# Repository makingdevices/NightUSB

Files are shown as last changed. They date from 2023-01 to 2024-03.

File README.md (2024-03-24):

<!-- Improved compatibility of back to top link: See: https://github.com/othneildrew/Best-README-Template/pull/73 -->

<!--
*** Thanks for checking out the Best-README-Template. If you have a suggestion
*** that would make this better, please fork the repo and create a pull request
*** or simply open an issue with the tag "enhancement".
*** Don't forget to give the project a star!
*** Thanks again! Now go create something AMAZING! :D
-->

<!-- PROJECT SHIELDS -->
<!--
*** I'm using markdown "reference style" links for readability.
*** Reference links are enclosed in brackets [ ] instead of parentheses ( ).
*** See the bottom of this document for the declaration of the reference variables
*** for contributors-url, forks-url, etc. This is an optional, concise syntax you may use.
*** https://www.markdownguide.org/basic-syntax/#reference-style-links
-->
[][ig-url]
[][sponsor-url]
[][stars-url]
[][issues-url]
[][linkedin-url]

<!-- PROJECT LOGO -->
<br />
<div align="center">
  <a href="https://makingdevices.com/links/">
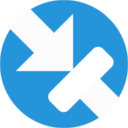
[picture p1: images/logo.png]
    
  </a>

<h3 align="center">Making Devices</h3>

  <p align="center">
    Open Source projects where we struggle with engineering, electronics, coding and who knows what else... Night USB is a very small USB dev board for the PIC18F14k50, so hopefully you may find it interesting ;)
  </p>
</div>

<!-- TABLE OF CONTENTS -->
<details>
  <summary>Table of Contents</summary>
  <ol>
    <li>
      <a href="#about-the-project">About The Project</a>
      <ul>
        <li><a href="#built-with">Built With</a></li>
      </ul>
    </li>
    <li>
      <a href="#Build-one">Build one</a>
      <ul>
      </ul>
    </li>
    <li><a href="#usage">Usage</a></li>
    <li><a href="#roadmap">Roadmap</a></li>
    <li><a href="#license">License</a></li>
    <li><a href="#contact">Contact</a></li>
    <li><a href="#Sponsor">Sponsor</a></li>
  </ol>
</details>

<!-- ABOUT THE PROJECT -->
## About The Project

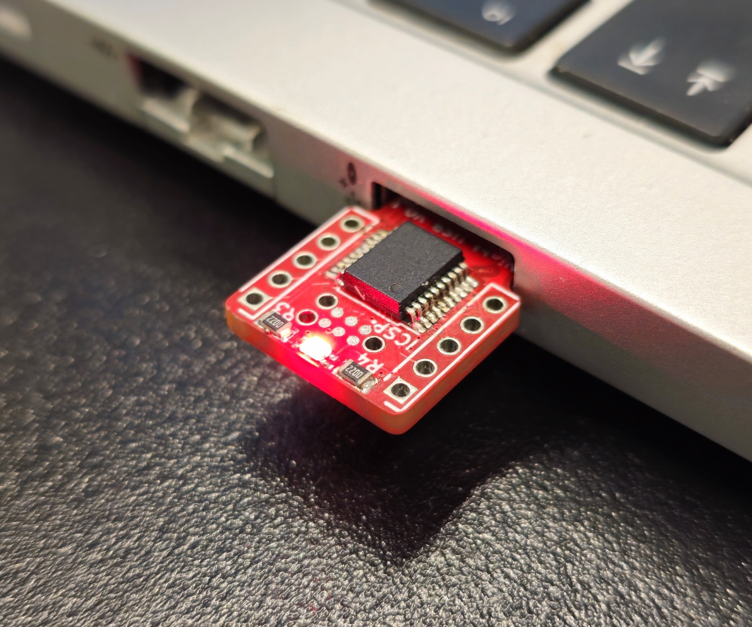
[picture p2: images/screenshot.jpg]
Bytes Counter Shot
[](https://makingdevices.com/NightUSB)

The PIC18F14k50 is USB-2.0 fully compatible, so this small dev board aims to explore the USB communication: Simulating mouse, keyboard, make small scripts for BADUSB behaviour... And so much else can be done with this microcontroller! However, it does not count on isolation between the PIC and the USB, so it should be handled quite carefully. 

On the other hand, most of the IO pins of the PIC18F are available in the board, so even if you dont have any project with an USB, you can use the board as a normal dev board.

This project is finished, and the provided .hex file and software code is tested. The code simulates a small movement of the mouse every 15s, with a small blink of the LED. This will keep your PC alive for longer sesions of automated tests or anything else. (NOT FOR Remote work abuse!!)

<p align="right">(<a href="#readme-top">back to top</a>)</p>

### Built With

[][PIC-url]
[][MPLAB-C-url]
[][kicad-url]
[][sponsor-url]

<p align="right">(<a href="#readme-top">back to top</a>)</p>

<!-- GETTING STARTED -->

## Build one
Documentation is updated.

1. Get the gerber files for the latest version: [V0.1](https://github.com/makingdevices/NightUSB/blob/main/Gerber/nightUSBv01.zip) 
2. Send them to a PCB manufacturer ([Our Sponsor is PCBWAY][sponsor-url])
3. You should solder all the components in the board. ([The schematic is available here v0.1][schematic-url])

<p align="right">(<a href="#readme-top">back to top</a>)</p>

<!-- USAGE EXAMPLES -->
## Usage

Instructions of use:

- The .hex files and software provided will emulate a mouse that will avoid your computer to go into sleep or standby.
- Dev Board. Only your imagination can tell you what to do with it :)

<p align="right">(<a href="#readme-top">back to top</a>)</p>

<!-- ROADMAP -->
## Roadmap

- [x] Finish the firmware for the PIC18F14K50
- [x] Assembly & First tests

See the [open issues](https://github.com/makingdevices/NightUSB/issues) for a full list of proposed features (and known issues).

State: Project <b>FINISHED</b> - 28/11/2023

<p align="right">(<a href="#readme-top">back to top</a>)</p>

<!-- LICENSE -->
## License

Distributed under three licenses:
- [Hardware](/License/HW_cern_ohl_s_v2.pdf)
- [Software](/License/SW_GPLv3.0.txt)
- [Documentation](/License/Documentation_CC-BY-SA-4.0.txt)

[GPL v3 License][license-url] 
<p align="right">(<a href="#readme-top">back to top</a>)</p>

<!-- CONTACT -->
## Contact

Making Devices - [@MakingDevices](https://www.instagram.com/makingdevices/)

Project Link: [https://github.com/makingdevices/NightUSB](https://github.com/makingdevices/NightUSB/)

Other Links: [LinkTree](https://makingdevices.com/links/)

<p align="right">(<a href="#readme-top">back to top</a>)</p>

<!-- Sponsor -->
## Sponsor

[PCBWAY](https://www.pcbway.com/?from=makingdevices) is the most professional PCB manufacturer for prototyping and low-volume production to work with in the world. With more than a decade in the field, They are committed to meeting the needs of their customers from different industries in terms of quality, delivery, cost-effectiveness and any other demanding requests. As Sponsor of Making Devices, they will be in charge of all the PCBs for MDV, allowing both of us to grow together in a long term partnership. We hope you take them into account for your both personal and professional prototypes or products.

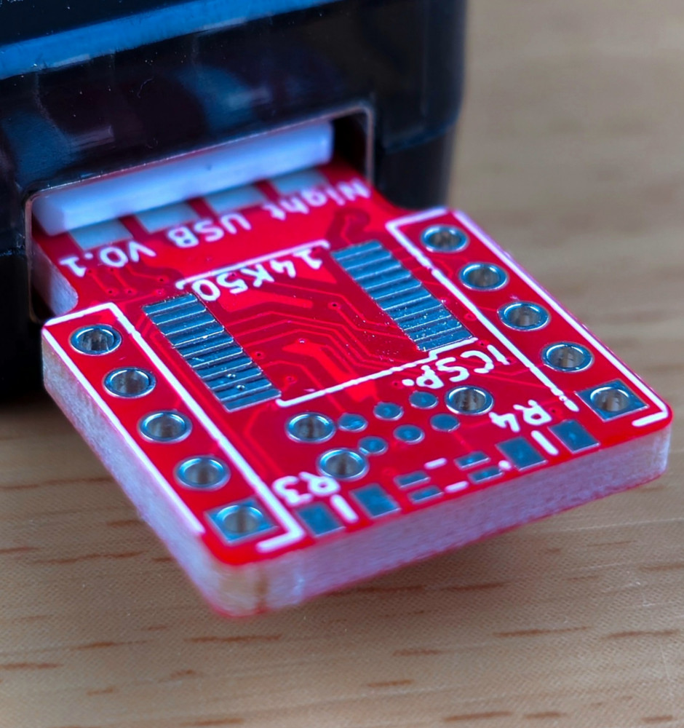
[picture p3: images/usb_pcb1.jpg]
[][sponsor-url]
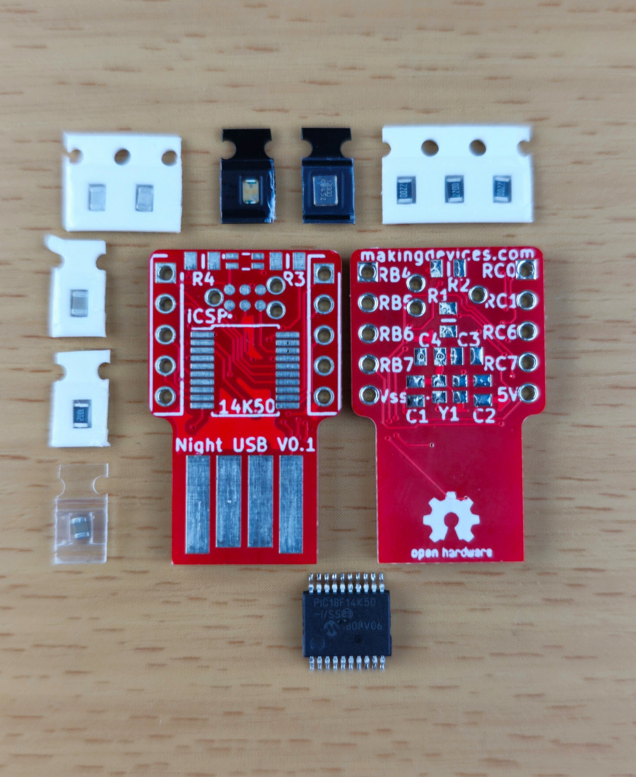
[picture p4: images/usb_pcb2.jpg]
[][sponsor-url]

<!-- MARKDOWN LINKS & IMAGES -->
<!-- https://www.markdownguide.org/basic-syntax/#reference-style-links -->
[contributors-shield]: https://img.shields.io/github/contributors/makingdevices/NightUSB.svg?style=for-the-badge
[contributors-url]: https://github.com/makingdevices/NightUSB/graphs/contributors
[forks-shield]: https://img.shields.io/github/forks/makingdevices/NightUSB.svg?style=for-the-badge
[forks-url]: https://github.com/makingdevices/NightUSB/network/members
[stars-shield]: https://img.shields.io/github/stars/makingdevices/NightUSB.svg?style=for-the-badge
[stars-url]: https://github.com/makingdevices/NightUSB/stargazers
[issues-shield]: https://img.shields.io/github/issues/makingdevices/NightUSB.svg?style=for-the-badge
[issues-url]: https://github.com/makingdevices/NightUSB/issues
[license-shield]: /images/license.png
[license-url]: https://github.com/makingdevices/NightUSB/tree/main/License
[linkedin-shield]: https://img.shields.io/badge/-LinkedIn-black.svg?style=for-the-badge&logo=linkedin&colorB=555
[linkedin-url]: https://www.linkedin.com/company/making-devices/
[sponsor-shield]: https://img.shields.io/badge/SPONSOR-PCBWAY-black.svg?style=for-the-badge&colorB=1200
[sponsor-url]: https://www.pcbway.com/?from=makingdevices
[sponsor-screenshot]: /images/PCB_sponsor.png
[sponsor-pcb-1]: /images/usb_pcb1.jpg
[sponsor-pcb-2]: /images/usb_pcb2.jpg
[product-screenshot]: images/screenshot.jpg
[PIC]: https://img.shields.io/badge/PIC18F14K50-000000?style=for-the-badge
[PIC-url]: http://ww1.microchip.com/downloads/en/devicedoc/40001350f.pdf
[kicad-shield]: https://img.shields.io/badge/kicad-0b03fc?style=for-the-badge&logo=kicad&logoColor=white
[kicad-url]: https://www.kicad.org/
[YT-screenshot]: images/YT_assembly.PNG
[sponsor-icon]:  https://img.shields.io/badge/-PCBWAY-black.svg?style=for-the-badge&colorB=1200
[ig-shield]: https://img.shields.io/badge/instagram-a83297?style=for-the-badge&logo=instagram&logoColor=white
[ig-url]: https://www.instagram.com/makingdevices/
[MPLAB-C]: https://img.shields.io/badge/MPLAB%20C18-DD0031?style=for-the-badge&logo=C&logoColor=white
[MPLAB-C-url]: https://www.microchip.com/en-us/development-tool/SW006011
[Svelte.dev]: https://img.shields.io/badge/Svelte-4A4A55?style=for-the-badge&logo=svelte&logoColor=FF3E00
[Svelte-url]: https://svelte.dev/
[Laravel.com]: https://img.shields.io/badge/Laravel-FF2D20?style=for-the-badge&logo=laravel&logoColor=white
[Laravel-url]: https://laravel.com
[Bootstrap.com]: https://img.shields.io/badge/Bootstrap-563D7C?style=for-the-badge&logo=bootstrap&logoColor=white
[Bootstrap-url]: https://getbootstrap.com
[JQuery.com]: https://img.shields.io/badge/jQuery-0769AD?style=for-the-badge&logo=jquery&logoColor=white
[JQuery-url]: https://jquery.com 
[schematic-url]: /Output_PDF/Schematic_V0_1.pdf

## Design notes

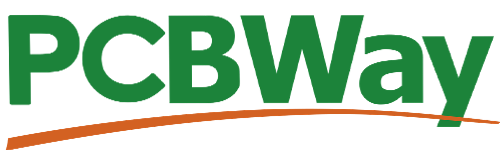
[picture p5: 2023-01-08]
images/PCB_sponsor.png

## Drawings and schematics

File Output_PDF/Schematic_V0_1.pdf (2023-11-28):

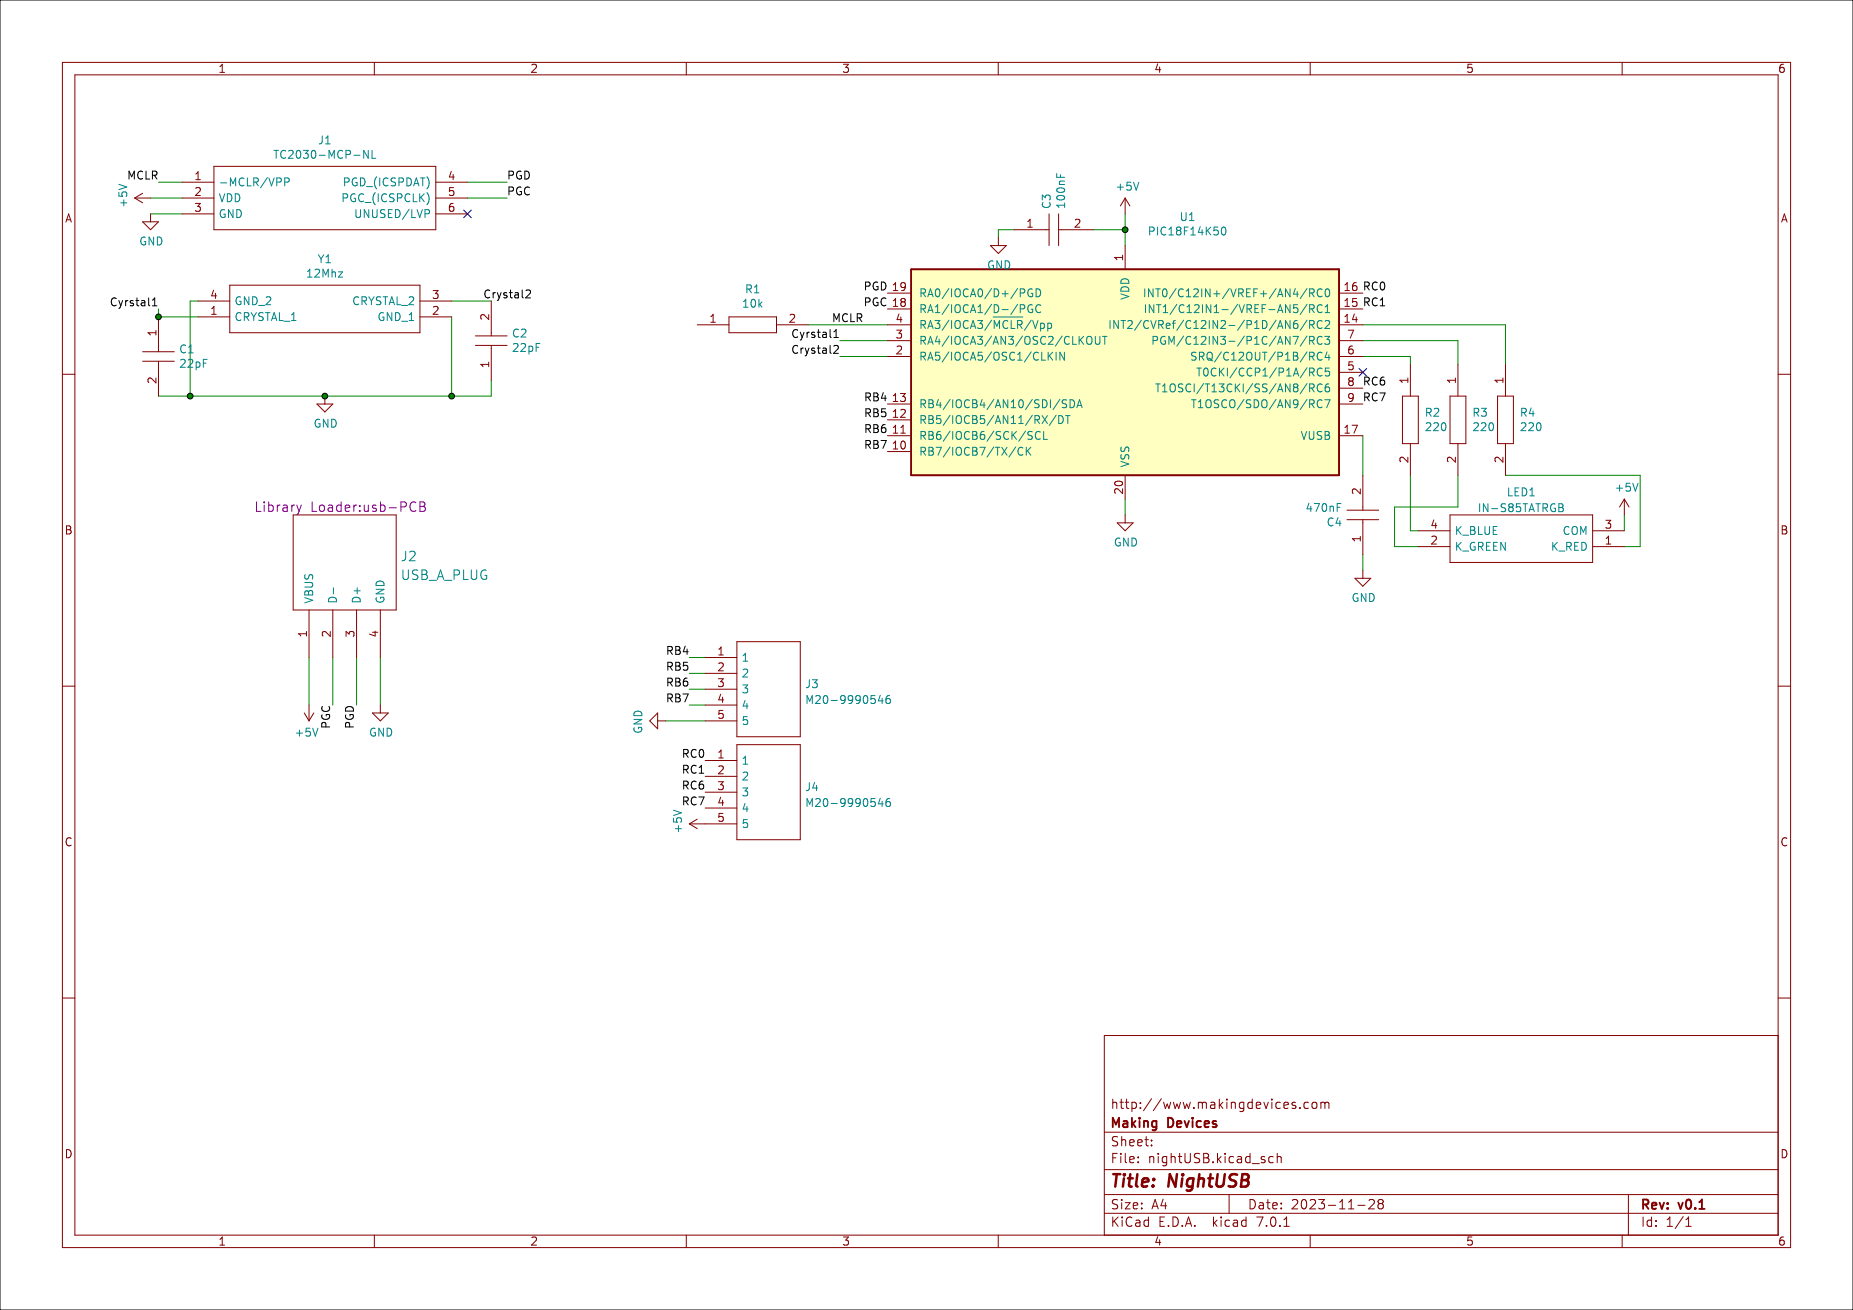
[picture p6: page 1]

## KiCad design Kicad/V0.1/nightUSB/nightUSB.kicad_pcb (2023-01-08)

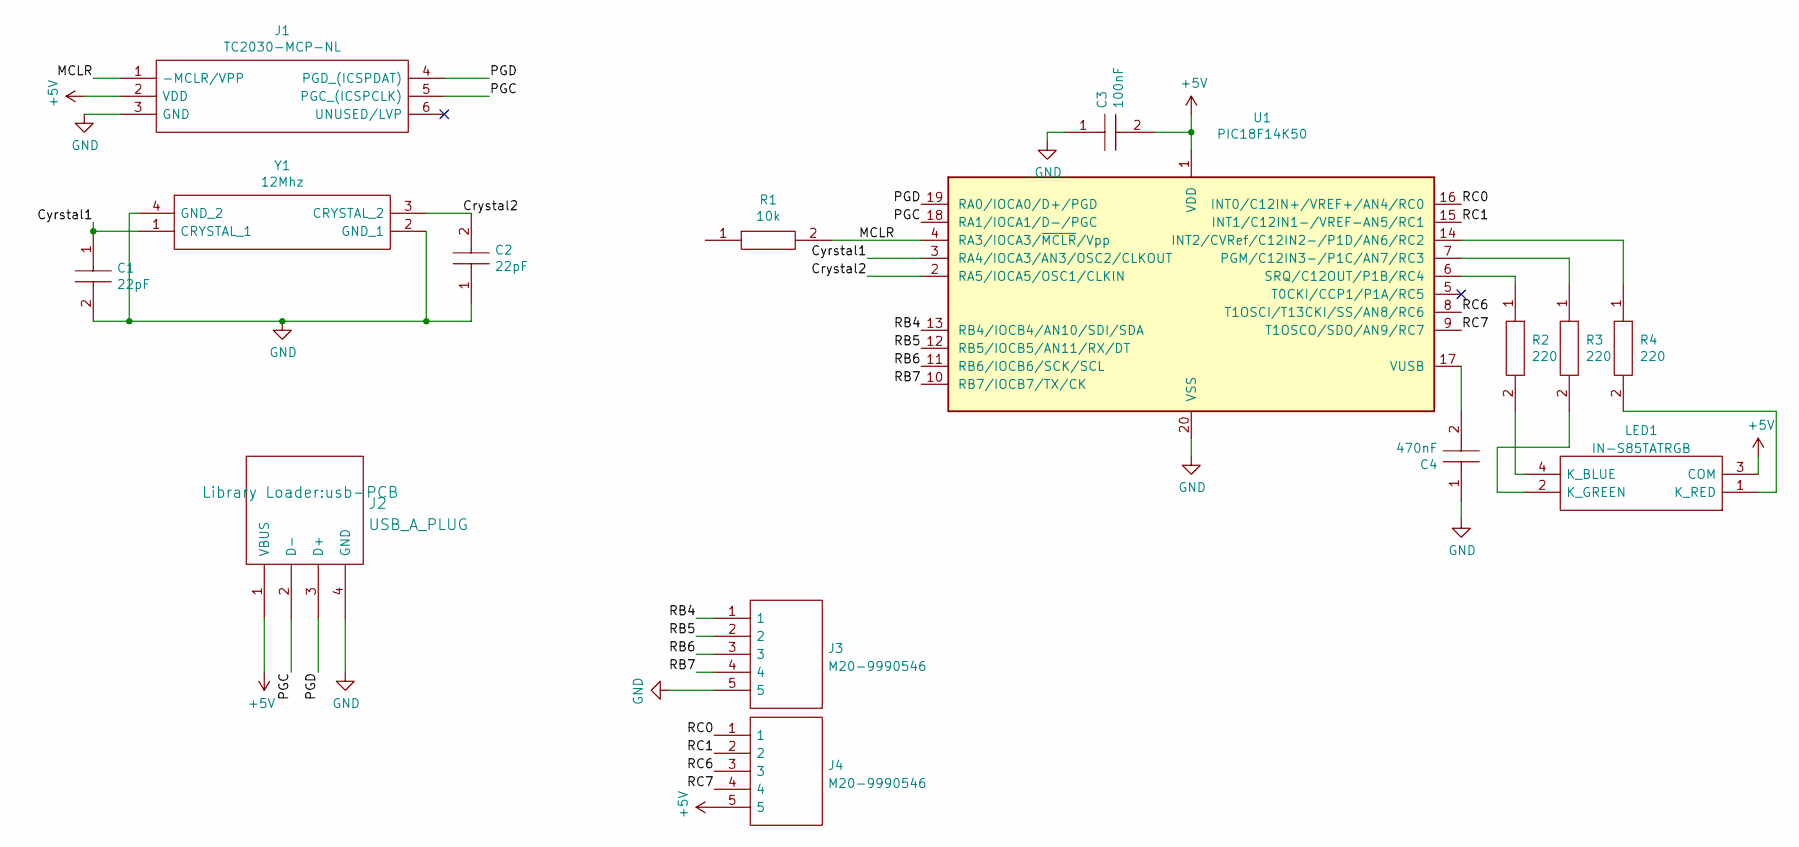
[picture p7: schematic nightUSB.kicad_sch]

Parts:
C1, C2: 22pF; CAPC2012X140N; Manufacturer_Part_Number C0805C475M8RACTU
C3: 100nF; CAPC2012X140N; Manufacturer_Part_Number C0805C475M8RACTU
C4: 470nF; CAPC2012X140N; Manufacturer_Part_Number C0805C475M8RACTU
J1: TC2030-MCP-NL; Manufacturer_Part_Number TC2030-MCP-NL
J2: USB_A_PLUG; usb-PCB
J3, J4: M20-9990546; HDRV5W64P0X254_1X5_1270X254X610P; Mouser Part Number 855-M20-9990546
LED1: IN-S85TATRGB; INS85DATRG; Mouser Part Number 743-IN-S85TATRGB
R1: 10k; RESC2012X75N; Manufacturer_Part_Number ERJP6WF1303V
R2, R3, R4: 220; RESC2012X75N; Manufacturer_Part_Number ERJP6WF1303V
U1: PIC18F14K50; SSOP-20_5.3x7.2mm_P0.65mm
Y1: 12Mhz; CX2520DB12000D0GPSC1; Manufacturer_Part_Number CX2520DB12000D0GPSC1

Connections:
+5V: C3.2, J1.2 (VDD), J2.1 (VBUS), J4.5, LED1.3 (COM), U1.1 (VDD)
/Crystal2: C2.2, U1.2 (RA5/IOCA5/OSC1/CLKIN), Y1.3 (CRYSTAL_2)
/Cyrstal1: C1.1, U1.3 (RA4/IOCA3/AN3/OSC2/CLKOUT), Y1.1 (CRYSTAL_1)
/MCLR: J1.1 (-MCLR/VPP), R1.2, U1.4 (RA3/IOCA3/~MCLR/Vpp)
/PGC: J1.5 (PGC_(ICSPCLK)), J2.2 (D-), U1.18 (RA1/IOCA1/D-/PGC)
/PGD: J1.4 (PGD_(ICSPDAT)), J2.3 (D+), U1.19 (RA0/IOCA0/D+/PGD)
/RB4: J3.1, U1.13 (RB4/IOCB4/AN10/SDI/SDA)
/RB5: J3.2, U1.12 (RB5/IOCB5/AN11/RX/DT)
/RB6: J3.3, U1.11 (RB6/IOCB6/SCK/SCL)
/RB7: J3.4, U1.10 (RB7/IOCB7/TX/CK)
/RC0: J4.1, U1.16 (INT0/C12IN+/VREF+/AN4/RC0)
/RC1: J4.2, U1.15 (INT1/C12IN1-/VREF-AN5/RC1)
/RC6: J4.3, U1.8 (T1OSCI/T13CKI/SS/AN8/RC6)
/RC7: J4.4, U1.9 (T1OSCO/SDO/AN9/RC7)
GND: C1.2, C2.1, C3.1, C4.1, J1.3 (GND), J2.4 (GND), J3.5, U1.20 (VSS), Y1.2 (GND_1), Y1.4 (GND_2)
unnamed: C4.2, U1.17 (VUSB)
unnamed: LED1.1 (K_RED), R4.2
unnamed: LED1.4 (K_BLUE), R2.2
unnamed: LED1.2 (K_GREEN), R3.2
unnamed: R2.1, U1.6 (SRQ/C12OUT/P1B/RC4)
unnamed: R3.1, U1.7 (PGM/C12IN3-/P1C/AN7/RC3)
unnamed: R4.1, U1.14 (INT2/CVRef/C12IN2-/P1D/AN6/RC2)

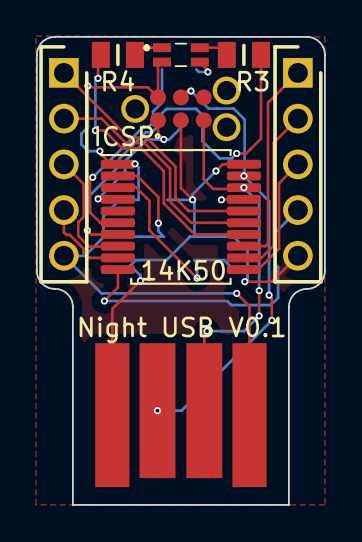
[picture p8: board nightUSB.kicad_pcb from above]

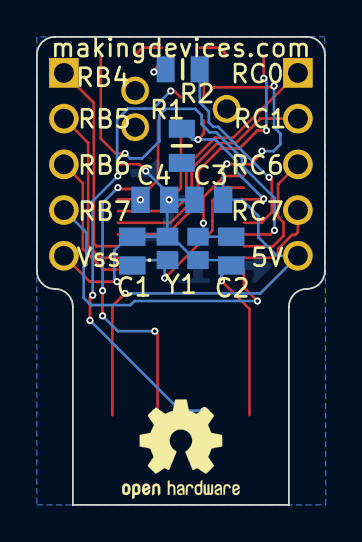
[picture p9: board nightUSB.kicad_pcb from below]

Board: 2 copper layers, 16.0 x 26.0 mm, 15 parts (7 on the bottom side), 22 nets.

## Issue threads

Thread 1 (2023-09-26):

USB Connection

makingdevices, 2023-09-26:
The device should be detected as a mouser hardware in any computer

**Design:**

- [x] The board has USB connector shape and can be inserted without any problem / causing shorts.

**Validate:**
- [x] The board is not loose and cannot produce any shorts.

makingdevices, 2023-09-28:
It was tested and works flawlessly

Closed 2023-09-28.

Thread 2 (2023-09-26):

Mouser functionality

makingdevices, 2023-09-26:
The device should be detected as a Mouser in the host PC.

**Design:**

- [x] The board move the mouse pointer for a couple of pixels every 10s.
- [x] The LED should blink when the mouse makes its movement.

**Validate:**

- [x] The device avoid the host computer to run into sleep or standby mode.
- [x] The device should not be appreciated from the user. The mouser should move a couple of pixels now and then.

makingdevices, 2023-11-28:
Everything tested and works like a charm. At the end I coded for a LED blink (and mouse movement) every 15s. Not appreciated for the user

Closed 2023-11-28.

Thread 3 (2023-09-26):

Assembly of the first iteration

makingdevices, 2023-09-26:
The first iteration of the PCB should be assembled to test if everything works as intended

**Design:**
- [x]  Release v0.1 PCB Version.
- [x] Order & Receive PCBs.
- [x] Assembly v0.1 PCB Version.

**Validate:**
- [x] The PCB has no problems or errors in the footprints and all the components are in stock.

makingdevices, 2023-09-26:
The PCBs were designed and already received. Assembly will happen soon

makingdevices, 2023-09-28:
Everything was assembled and fully operational

Closed 2023-09-28.
